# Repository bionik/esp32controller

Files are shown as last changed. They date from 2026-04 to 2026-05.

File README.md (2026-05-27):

# esp32controller

WiFi-enabled ESP32S3 game controller interface with WebSocket control, Bluetooth gamepad support, and OTA firmware updates.

The ESP32S3 runs a small HTTP/WebSocket server for remote control of GPIO pins, and also supports Bluetooth controllers through Bluepad32. The design is aimed at controlling classic systems such as the Amiga, with the option to adapt to other consoles if properly powered and filtered.

Features:
* WiFi connection using credentials from `firmware/src/credentials.h` or fallback defaults.
* WebSocket server at `/ws` for remote button press/release commands.
* ElegantOTA support with authenticated OTA updates.
* Bluetooth controller support using Bluepad32.
* Boot-button pairing mode: long-press the BOOT button to enter Bluetooth pairing.
* Only the last paired Bluetooth controller is accepted after pairing mode, all others are rejected.
* GPIO safety fallback: all control pins are reset when WiFi, WebSocket, or Bluetooth disconnects.
* Phone keypad mapping on websocket: numeric keys `2/4/6/8` map to directions and `1/3/5` map to buttons.
* Built-in RGB LED status reporting for connection states and pairing.

LED color guide:
* Green: idle / no WiFi and no Bluetooth connected.
* Red: WiFi connected but no WebSocket client and no Bluetooth controller.
* Yellow: WiFi connected and WebSocket client connected.
* Blue: Bluetooth controller connected.
* Magenta: WiFi connected and Bluetooth connected, but no WebSocket client.
* White: WiFi, WebSocket, and Bluetooth all connected.
* Fast blinking blue: Bluetooth pairing mode active.

Firmware notes:
* Control pins are defined in `firmware/src/main.cpp` and are driven LOW by default for safety.
* WiFi tries to reconnect automatically after a delay.
* Bluetooth pairing mode times out after 20 seconds if no device is found.
* On OTA start, GPIOs are reset and the device restarts after a successful update.

## Project Files

- **Hardware**: KiCad PCB design files (`esp32controller.kicad_*`) with custom ESP32S3 Supermini footprint
- **Firmware**: PlatformIO project in `firmware/` with WiFi server, WebSocket control, Bluepad32, and ElegantOTA support
- **Libraries**: Custom symbol (`project_parts.kicad_sym`) and footprint (`project_parts.pretty/`) libraries

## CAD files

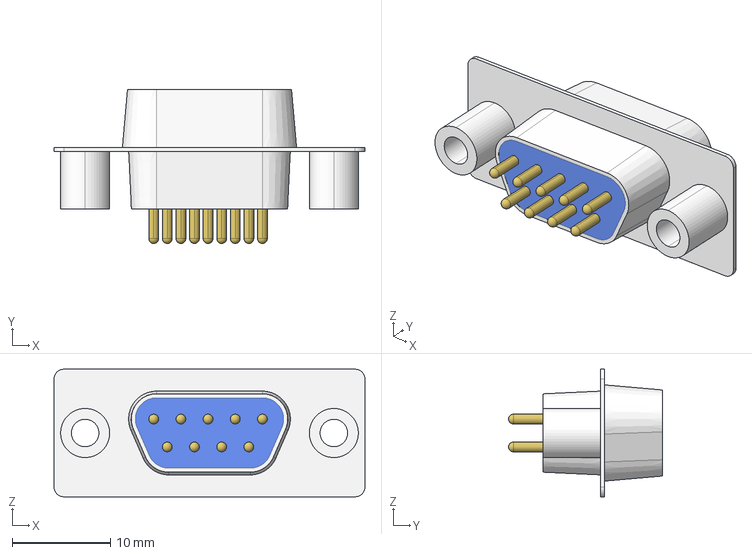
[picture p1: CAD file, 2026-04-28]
3dmodels/DB9-pins.step
31.7 x 15.7 x 13.0 mm

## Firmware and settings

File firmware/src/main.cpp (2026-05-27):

#include <Arduino.h>
#include <WiFi.h>
#include <ESPAsyncWebServer.h>
#include <ElegantOTA.h>
#include <Bluepad32.h>
#include <cstring>
#include <Preferences.h>

Preferences preferences;
uint8_t lastConnectedAddr[6] = {0, 0, 0, 0, 0, 0};
bool hasStoredDevice = false;

// Try to include credentials from separate file
// If credentials.h doesn't exist, fall back to defaults below
#if __has_include("credentials.h")
    #include "credentials.h"
#else
    #warning "credentials.h not found, using default credentials"
    #define WIFI_SSID "YOUR_WIFI_SSID"
    #define WIFI_PASSWORD "YOUR_WIFI_PASSWORD"
    #define OTA_USERNAME "admin"
    #define OTA_PASSWORD "secure123"
#endif

// Debug flag - set to 0 to disable debug prints
#define DEBUG 1

// Built-in RGB LED Configuration
#define LED_BRIGHTNESS 16  // Brightness (0-255)

// Boot button configuration
#define BOOT_BUTTON 0  // GPIO 0 is typically the BOOT button on ESP32
#define PAIRING_HOLD_TIME 2200  // How long press to enter pairing mode
#define PAIRING_TIMEOUT 20000   // 20 seconds pairing timeout
#define PAIRING_BLINK_INTERVAL 100  // Fast blink interval in ms

// WiFi reconnection configuration
#define WIFI_RECONNECT_DELAY 5000  // Delay in milliseconds before attempting to reconnect

// Connection state variables
bool wifiConnected = false;
bool wsConnected = false;
bool btConnected = false;
unsigned long lastWiFiDisconnectTime = 0;  // Timestamp of last WiFi disconnection

// Pairing mode variables
bool pairingMode = false;
unsigned long pairingStartTime = 0;
unsigned long lastBlinkTime = 0;
bool blinkState = false;

// Button state tracking
bool buttonPressed = false;
unsigned long buttonPressStart = 0;

void setLedColor(int r, int g, int b) {
#ifdef RGB_BUILTIN
    neopixelWrite(RGB_BUILTIN, r, g, b);
#endif
}

void updateLedState() {
    // Pairing mode overrides all other LED states with fast blinking blue
    if (pairingMode) {
        unsigned long currentTime = millis();
        if (currentTime - lastBlinkTime >= PAIRING_BLINK_INTERVAL) {
            blinkState = !blinkState;
            lastBlinkTime = currentTime;
            if (blinkState) {
                setLedColor(0, 0, LED_BRIGHTNESS);  // Blue
            } else {
                setLedColor(0, 0, 0);  // Off
            }
        }
        return;
    }
    
    // Normal LED state based on connections
    int ledState = (wifiConnected << 2) | (wsConnected << 1) | (btConnected);
    switch (ledState) {
        case 0b000: 
            setLedColor(0, LED_BRIGHTNESS, 0);   // Green (Idle)
            break;
        case 0b100: 
            setLedColor(LED_BRIGHTNESS, 0, 0);   // Red (WiFi only)
            break;
        case 0b110: 
            setLedColor(LED_BRIGHTNESS, LED_BRIGHTNESS, 0); // Yellow (WiFi + WS)
            break;
        case 0b001: 
            setLedColor(0, 0, LED_BRIGHTNESS);   // Blue (BT only)
            break;
        case 0b101: 
            setLedColor(LED_BRIGHTNESS, 0, LED_BRIGHTNESS); // Magenta (WiFi + BT)
            break;
        case 0b111: 
            setLedColor(LED_BRIGHTNESS, LED_BRIGHTNESS, LED_BRIGHTNESS); // White (All)
            break;
        default:
            setLedColor(0, LED_BRIGHTNESS, 0);   // Default to green
            break;
    }
}

const char* ssid = WIFI_SSID;
const char* password = WIFI_PASSWORD;
const char* ota_user = OTA_USERNAME;
const char* ota_pass = OTA_PASSWORD; 

void resetPins();
void setControlPin(const char* label, bool state);

void onWiFiEvent(WiFiEvent_t event) {
    switch (event) {
        case SYSTEM_EVENT_STA_GOT_IP:
            wifiConnected = true;
            if (DEBUG) Serial.printf("WiFi connected: %s\n", WiFi.localIP().toString().c_str());
            updateLedState();
            break;
        case SYSTEM_EVENT_STA_DISCONNECTED:
            if (wifiConnected) {
                wifiConnected = false;
                if (DEBUG) Serial.println("WiFi disconnected");
                resetPins();
                updateLedState();
            }
            break;
        default:
            break;
    }
}

struct ControlBinding {
    const char* label;
    int pin;
};

ControlBinding controlPins[] = {
    {"up",      11},
    {"down",    13},
    {"left",    10},
    {"right",   1},
    {"button1", 9},
    {"button2", 7},
    {"button3", 3}
};

const int numControls = sizeof(controlPins) / sizeof(controlPins[0]);
// Phone keypad -> control label translation (index = digit)
// 2 -> up, 4 -> left, 6 -> right, 8 -> down,
// 1 -> button1, 3 -> button2, 5 -> button3
const char* phoneMap[10] = {
    nullptr,      // 0
    "button1",   // 1
    "up",        // 2
    "button2",   // 3
    "left",      // 4
    "button3",   // 5
    "right",     // 6
    nullptr,      // 7
    "down",      // 8
    nullptr       // 9
};
AsyncWebServer server(80);
AsyncWebSocket ws("/ws");

// Currently connected Bluetooth controller (if any)
ControllerPtr activeController = nullptr;

void resetPins() {
    for (int i = 0; i < numControls; i++) {
        digitalWrite(controlPins[i].pin, LOW);
    }
    if (DEBUG) Serial.println("GPIOs Reset for safety");
}

// --- OTA Callback Functions ---
void onOTAStart() {
    Serial.println("OTA Update started!");
    resetPins(); // Kill all GPIOs before update begins
}

void onOTAEnd(bool success) {
    if (success) {
        Serial.println("OTA Update finished successfully!");
        delay(1000); 
        ESP.restart(); 
    } else {
        Serial.println("OTA Update failed!");
        resetPins();
    }
}

void handleCommand(String message) {
    message.trim();
    if (DEBUG) Serial.println("Message received: " + message);
    
    if (message == "connect" || message == "disconnect") {
        resetPins();
        return;
    }

    int separatorIdx = message.indexOf(':');
    if (separatorIdx == -1) return;

    String label = message.substring(0, separatorIdx);
    String action = message.substring(separatorIdx + 1);
    bool state = (action == "down");

    // Translate numeric phone keypad inputs (e.g. "8:down") to control labels
    const char* resolvedLabel = label.c_str();
    if (label.length() == 1) {
        char c = label.charAt(0);
        if (c >= '0' && c <= '9') {
            const char* mapped = phoneMap[c - '0'];
            if (mapped != nullptr) {
                resolvedLabel = mapped;
                if (DEBUG) Serial.printf("Translated phone key '%c' -> %s\n", c, resolvedLabel);
            } else {
                if (DEBUG) Serial.printf("Phone key '%c' has no mapping, ignoring\n", c);
                return; // ignore unmapped numeric keys
            }
        }
    }

    setControlPin(resolvedLabel, state);
}

void setControlPin(const char* label, bool state) {
    if (DEBUG) Serial.printf("setControlPin called: '%s' -> %s\n", label, state ? "true" : "false");
    for (int i = 0; i < numControls; i++) {
        if (strcmp(label, controlPins[i].label) == 0) {
            digitalWrite(controlPins[i].pin, state ? HIGH : LOW);
            if (DEBUG) Serial.printf("Control '%s' -> %s (GPIO %d)\n", label, state ? "HIGH" : "LOW", controlPins[i].pin);
            return;
        }
    }
    if (DEBUG) Serial.printf("Unknown control '%s'\n", label);
}

void onEvent(AsyncWebSocket *server, AsyncWebSocketClient *client, AwsEventType type,
             void *arg, uint8_t *data, size_t len) {
    if (DEBUG) {
        if (client) {
            Serial.printf("WebSocket event %u for client #%u\n", type, client->id());
        } else {
            Serial.printf("WebSocket event %u\n", type);
        }
    }
    switch (type) {
        case WS_EVT_CONNECT:
            if (DEBUG) Serial.printf("WebSocket client #%u connected\n", client->id());
            wsConnected = true;
            updateLedState();
            resetPins();
            break;

        case WS_EVT_DISCONNECT:
            if (DEBUG) Serial.printf("WebSocket client #%u disconnected\n", client->id());
            wsConnected = false;
            updateLedState();
            resetPins();
            break;

        case WS_EVT_DATA: {
            AwsFrameInfo *info = (AwsFrameInfo*)arg;
            if (info->final && info->index == 0 && info->len == len && info->opcode == WS_TEXT) {
                char* tempBuffer = (char*)malloc(len + 1);
                if (tempBuffer) {
                    memcpy(tempBuffer, data, len);
                    tempBuffer[len] = '\0';
                    handleCommand(String(tempBuffer));
                    free(tempBuffer);
                }
            }
            break;
        }
            
        case WS_EVT_PONG:
        case WS_EVT_ERROR:
            break;
    }
}

void startPairingMode() {
    if (DEBUG) {
        Serial.println("=== Entering pairing mode ===");
        Serial.println("Forgetting all paired devices and enabling scanning...");
    }
    
    pairingMode = true;
    pairingStartTime = millis();
    lastBlinkTime = 0;
    blinkState = false;
    
    // Explicitly reset BT states
    activeController = nullptr;
    btConnected = false;
    resetPins();
    
    BP32.forgetBluetoothKeys();
    BP32.enableNewBluetoothConnections(true);
    
    if (DEBUG) Serial.println("Pairing mode active - put your controller in pairing mode now!");
    
    updateLedState();
}

void stopPairingMode(bool success) {
    if (DEBUG) {
        if (success) {
            Serial.println("=== Pairing mode ended - device connected ===");
        } else {
            Serial.println("=== Pairing mode timeout - no device found ===");
            Serial.println("Disabling new Bluetooth connections");
            BP32.enableNewBluetoothConnections(false);
        }
    }
    pairingMode = false;
    updateLedState();
}

void onConnectedBTController(ControllerPtr ctl) {
    ControllerProperties properties = ctl->getProperties();
    const uint8_t* currentAddr = properties.btaddr;

    if (DEBUG) {
        Serial.println("=== Bluetooth Controller Attempting Connection ===");
        Serial.printf("MAC: %02x:%02x:%02x:%02x:%02x:%02x\n", 
                      currentAddr[0], currentAddr[1], currentAddr[2], 
                      currentAddr[3], currentAddr[4], currentAddr[5]);
    }

    if (pairingMode) {
        if (DEBUG) Serial.println("Pairing mode active. Saving this device as the new 'last connected'.");
        
        preferences.begin("bp32-config", false);
        preferences.putBytes("last-mac", currentAddr, 6);
        preferences.end();
        
        memcpy(lastConnectedAddr, currentAddr, 6);
        hasStoredDevice = true;
        
        if (DEBUG) Serial.println("Disabling new Bluetooth connections");
        BP32.enableNewBluetoothConnections(false);
        stopPairingMode(true);
    } else {
        if (!hasStoredDevice || memcmp(currentAddr, lastConnectedAddr, 6) != 0) {
            if (DEBUG) Serial.println("Rejected: Device does not match the last connected MAC. Kicking off...");
            ctl->disconnect();
            return; 
        }
        if (DEBUG) Serial.println("Welcome back! Last connected device verified.");
    }

    if (DEBUG) Serial.printf("Controller model: %s\n", ctl->getModelName().c_str());
    
    // Assign the active controller. (The main loop logic handles btConnected and LED triggers)
    activeController = ctl;
}

void onDisconnectedBTController(ControllerPtr ctl) {
    if (DEBUG) {
        Serial.println("=== Bluetooth Controller disconnected ===");
    }
    // Clean up the pointer reference. Loop will notice this and flip flags.
    if (activeController == ctl) {
        activeController = nullptr;
    }
}

void setup() {
    Serial.begin(115200);

    if (DEBUG) Serial.println("Booting esp32controller...");

    preferences.begin("bp32-config", true);
    if (preferences.isKey("last-mac")) {
        preferences.getBytes("last-mac", lastConnectedAddr, 6);
        hasStoredDevice = true;
        if (DEBUG) {
            Serial.printf("Loaded last connected MAC: %02x:%02x:%02x:%02x:%02x:%02x\n",
                          lastConnectedAddr[0], lastConnectedAddr[1], lastConnectedAddr[2], 
                          lastConnectedAddr[3], lastConnectedAddr[4], lastConnectedAddr[5]);
        }
    } else {
        if (DEBUG) Serial.println("No previously connected device found in memory.");
    }
    preferences.end();

#ifdef RGB_BUILTIN
    pinMode(RGB_BUILTIN, OUTPUT);
#endif
    updateLedState(); 
    
    pinMode(BOOT_BUTTON, INPUT_PULLUP);

    for (int i = 0; i < numControls; i++) {
        pinMode(controlPins[i].pin, OUTPUT);
    }
    resetPins();
    delay(200); 

    if (DEBUG) Serial.printf("Connecting to WiFi SSID '%s'...\n", ssid);
    WiFi.mode(WIFI_STA);
    WiFi.setAutoReconnect(false);  
    WiFi.onEvent(onWiFiEvent);

    delay(500); 

    WiFi.begin(ssid, password);

    server.on("/", HTTP_GET, [](AsyncWebServerRequest *request){
        request->send(200, "text/plain", "Hello! Connect with websocket to control the device.");
    });

    ws.onEvent(onEvent);
    server.addHandler(&ws);
    if (DEBUG) Serial.println("WebSocket handler attached at /ws");
    
    ElegantOTA.begin(&server, ota_user, ota_pass); 
    ElegantOTA.onStart(onOTAStart);
    ElegantOTA.onEnd(onOTAEnd);

    // Initialize Bluepad32
    BP32.setup(&onConnectedBTController, &onDisconnectedBTController);
    BP32.enableNewBluetoothConnections(true); // Open the door; our filter bouncer manages the checks
    
    server.begin();

    if (DEBUG) Serial.println("Ready. Awaiting connections...");
}

void loop() {
    BP32.update();

    // ----------------------------------------------------
    // Active Bluetooth State Monitoring
    // ----------------------------------------------------
    bool currentBtState = (activeController != nullptr && activeController->isConnected());
    if (currentBtState != btConnected) {
        btConnected = currentBtState;
        if (DEBUG) {
            Serial.printf("Bluetooth state synced: %s\n", btConnected ? "CONNECTED" : "DISCONNECTED");
        }
        if (!btConnected) {
            resetPins(); // Safety fallback if connection drops
        }
        updateLedState();
    }

    // If a Bluetooth controller is connected, poll its state and map to controls
    if (activeController && activeController->hasData()) {
        uint8_t d = activeController->dpad();
        bool up = (d & DPAD_UP);
        bool down = (d & DPAD_DOWN);
        bool left = (d & DPAD_LEFT);
        bool right = (d & DPAD_RIGHT);

        setControlPin("up", up);
        setControlPin("down", down);
        setControlPin("left", left);
        setControlPin("right", right);

        setControlPin("button1", activeController->a());
        setControlPin("button2", activeController->b() || activeController->x());
        setControlPin("button3", activeController->y());
    }
    
    ElegantOTA.loop();
    ws.cleanupClients();
    
    // Handle boot button for pairing mode
    bool currentButtonState = (digitalRead(BOOT_BUTTON) == LOW);  
    
    if (currentButtonState && !buttonPressed) {
        buttonPressed = true;
        buttonPressStart = millis();
    } else if (!currentButtonState && buttonPressed) {
        buttonPressed = false;
    } else if (buttonPressed && !pairingMode) {
        if (millis() - buttonPressStart >= PAIRING_HOLD_TIME) {
            startPairingMode();
            buttonPressed = false;  
        }
    }
    
    // Check pairing mode timeout
    if (pairingMode) {
        if (millis() - pairingStartTime >= PAIRING_TIMEOUT) {
            stopPairingMode(false);  
        }
    }
    
    // Monitor WiFi connection state
    bool currentWifiState = (WiFi.status() == WL_CONNECTED);
    if (currentWifiState != wifiConnected) {
        wifiConnected = currentWifiState;
        if (!wifiConnected) {
            if (DEBUG) Serial.println("WiFi disconnected");
            lastWiFiDisconnectTime = millis();
            resetPins(); 
        } else {
            if (DEBUG) Serial.printf("WiFi connected: %s\n", WiFi.localIP().toString().c_str());
        }
        updateLedState();
    }
    
    // Attempt WiFi reconnection after delay if disconnected
    if (!wifiConnected && (millis() - lastWiFiDisconnectTime >= WIFI_RECONNECT_DELAY)) {
        if (DEBUG) Serial.println("Attempting WiFi reconnection...");
        WiFi.reconnect();
    }
    
    // Monitor WebSocket connection state
    bool currentWsState = (ws.count() > 0);
    if (currentWsState != wsConnected) {
        wsConnected = currentWsState;
        if (!wsConnected && DEBUG) {
            Serial.println("All WebSocket clients disconnected");
        }
        updateLedState();
    }
    
    // Update LED state continuously (needed for blinking in pairing mode)
    if (pairingMode) {
        updateLedState();
    }
}

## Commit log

2026-04-21 Add project files
    [esp32controller.kicad_pcb, esp32controller.kicad_sch]
2026-04-21 Added firmware, cleaned files
    [esp32controller.kicad_pcb]
2026-04-21 Added project parts
    [esp32controller.kicad_sch]
2026-04-21 Updated footprint/schematic references
    [esp32controller.kicad_sch]
2026-04-22 Fixes to kicad files
    [esp32controller.kicad_pcb, esp32controller.kicad_sch]
2026-04-22 Updates to pcb
    [esp32controller.kicad_pcb]
2026-04-28 Added 3d model for dsub9, goodmicros logo
    [DB9-pins.step]
2026-04-28 Final touches before ordering rev1
    [esp32controller.kicad_pcb]
2026-05-06 Changes to readme, added Bluepad32 and pairing button code, led states
2026-05-19 Added pin logic
2026-05-20 Add OTA compatible partition scheme
    [partitions.csv]
2026-05-27 Fixes to bt connectivity, partition
    [main.cpp]
